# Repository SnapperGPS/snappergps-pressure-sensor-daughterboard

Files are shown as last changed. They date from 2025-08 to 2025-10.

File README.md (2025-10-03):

# snappergps-pressure-sensor-daughterboard

*Author: Jonas Beuchert*

Pressure sensor daughter-board for SnapperGPS receiver (v1.0.x or v2.0.x).

## Table of contents

* [Files](#files)
* [Manufacturing](#manufacturing)
* [Components](#components)
* [Assembly](#assembly)
* [Flashing](#flashing)
* [Usage](#usage)
* [Acknowledgements](#acknowledgements)

## Files

*Note:* There are two releases of the daughter-board, v1.0 and v2.0.
While v1.0 is tested, it has a bug that prevents it from being soldered directly onto a SnapperGPS receiver without use of additional wires.
In contrast, v2.0 fixes this bug, but has not been tested yet.

* `gerber`: Gerber files and drill file for manufacturing the daughter-board.
* `bom.csv`: Bill of materials of the daughter-board components.
* `pcb.json`: PCB layout file of the daughter-board. Created with EasyEDA.
* `pick-and-place.csv`: Centroid / pick-and-place file for assembly.
* `schematic.json`: Schematic file of the daughter-board. Created with EasyEDA.
* `schematic.pdf`: Schematic as PDF.

## Manufacturing

* Get some PCBs manufactured by a PCB manufacturer of your choice.
(I used [JLCPCB](https://jlcpcb.com), [Aisler](https://aisler.net/), or [PCBWay](https://www.pcbway.com/) in the past.)
For this, upload the `gerber` folder to the manufacturer's website.
Choose a two-layered PCB with size 3.56 mm x 11.68 mm.

* If you want, you can also let the manufacturer assemble the board(s) for you.

## Components

| designator | quantity | description | footprint | manufacturer part | manufacturer | supplier | supplier part | price |
|---|---:|---|---|---|---|---|---|---:|
| C30 | 1 | 100 nF capacitor | 0402 | CL05B104KO5NNNC | SAMSUNG | LCSC | C1525 | $0.001  |
| U2 | 1 | pressure sensor  | | MS583730BA01-50 | TE Connectivity  | LCSC | C2887941 | $11.391 |
| R32, R34 | 2 | 10 kΩ resistor | 0402 | 0402WGF1002TCE | UNI-ROYAL | LCSC | C25744 | $0.001  |

*Note:* Most other SMD capacitors and resistors with the same value and footprint will also work.

*Note:* Instead of a pressure sensor from the [MS5837-30BA series](https://www.te.com/commerce/DocumentDelivery/DDEController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) pressure sensor, you can also use a pressure sensor from the [MS5837-02BA series](https://www.te.com/commerce/DocumentDelivery/DDEController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). The MS5837-30BA series measures pressures up to 30 bar (~300 m depth), while the MS5837-02BA series is limited to 2 bar (10 m). However, it may be more suitable for measurements in air or shallow water, but you would need to adjust the firmware yourself.

## Assembly

* Solder the two resistors, the capacitor, and the pressure sensor on the daughterboard.
Ensure that the marked corner of the pressure sensor is aligned with the mark on the PCB.
I recommend solder paste and a hot plate (or hot air gun) for soldering.

* Solder the assembled daughter-board on a SnapperGPS receiver.
Note that only version v1.0.x and v2.0.x are compatible, **not** v2.1.x or 2.2.x).
The five pads on the back of the daughter-board should connect to the five pads on the SnapperGPS receiver.
The daughter-baord shall be orientated such that the pressure sensor sits in the corner of the SnapperGPS receiver.

* Package the whole assembly in a water/weather-proof way, which still exposes the gel-filled cavity of the pressure sensor.
For example, I used silicon potting for this, but you can also use a rigid housing with a 3.07 mm hole combined with an O-ring with inner diameter 1.8 mm and cross-section diameter 0.8 mm.

## Flashing

* Go to [https://snappergps.info/flash](https://snappergps.info/flash) or [https://snappergps.github.io/snappergps-app-lite/flash](https://snappergps.github.io/snappergps-app-lite/flash).
* Connect the SnapperGPS receiver to your computer via USB.
* Pair the SnapperGPS receiver.
* Select the `SnapperGPS-PressureSensor` firmware.
* Flash the firmware.

## Usage

Find instructions in the firmware repository.



## Acknowledgements

This SnapperGPS daughter-board was developed by
[Jonas Beuchert](https://profiles.cardiff.ac.uk/staff/beuchertj)
in the School of Computer Science and Informatics
of Cardiff University.

This repository is licensed under a
[Creative Commons Attribution 3.0 International License][cc-by].

[][cc-by]

[cc-by]: http://creativecommons.org/licenses/by/3.0/
[cc-by-image]: https://i.creativecommons.org/l/by/3.0/88x31.png

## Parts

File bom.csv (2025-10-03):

ID | Name | Designator | Footprint | Quantity | Manufacturer Part | Manufacturer | Supplier | Supplier Part | Price
1 | 100nF | C30 | C0402 | 1 | CL05B104KO5NNNC | SAMSUNG(三星) | LCSC | C1525 | 0.001
2 | MS583730BA01-50 | U2 | SENSOR-SMD_4P-L3.3-W3.3-P2.00-BL | 1 | MS583730BA01-50 | TE Connectivity(泰科电子) | LCSC | C2887941 | 11.391
3 | 10kΩ | R32,R34 | R0402 | 2 | 0402WGF1002TCE | UNI-ROYAL(厚声) | LCSC | C25744 | 0.001

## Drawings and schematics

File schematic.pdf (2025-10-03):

# Pressure Sensor

# GPIOs

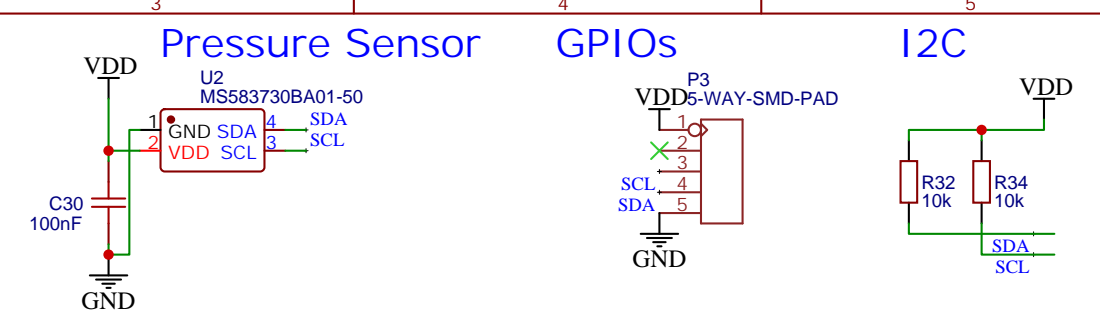
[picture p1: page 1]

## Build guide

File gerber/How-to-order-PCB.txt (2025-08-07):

How to Order PCB

Please refer to:
https://docs.easyeda.com/en/PCB/Order-PCB

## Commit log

2025-08-07 Add design files, BOM, and pick-and-place file
    [bom.csv, pick-and-place.csv]
2025-08-07 Add gerber manufacturing files
    [Drill_PTH_Through.DRL, Drill_PTH_Through_Via.DRL, Gerber_BoardOutlineLayer.GKO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]
2025-08-08 Update README.md with file description and BOM
2025-08-08 Update README.md with assembly instructions
2025-10-03 Remove SMD pads from bill of materials
    [bom.csv, pick-and-place.csv]
2025-10-03 Switch GND and VDD
    [Drill_PTH_Through.DRL, Drill_PTH_Through_Via.DRL, Gerber_BoardOutlineLayer.GKO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]

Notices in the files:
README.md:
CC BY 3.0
